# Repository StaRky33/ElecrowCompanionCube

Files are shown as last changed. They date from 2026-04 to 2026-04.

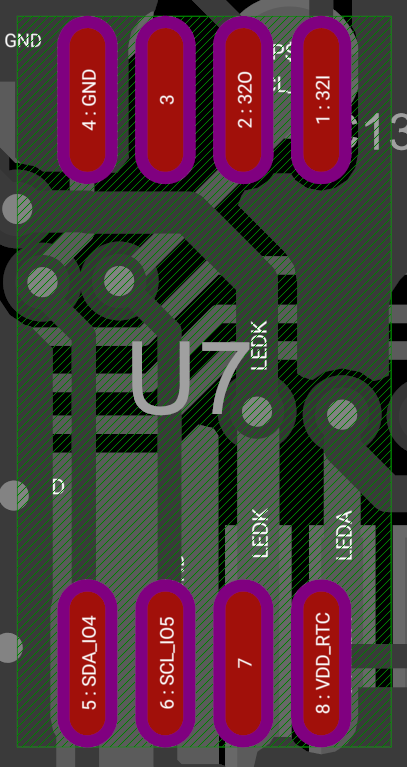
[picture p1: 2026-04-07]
Docs/PCB_BM8563_pinout.png

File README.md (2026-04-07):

# Elecrow Companion Cube

A DIY smart desk clock built on the **Elecrow CrowPanel ESP32 1.28" Round Display**, inspired by [Huy Vector's Smart Cyber Clock V2](https://www.huyvector.org/smart-cyber-clock-v2) and shaped like a Portal Companion Cube.

Displays real-time clock, temperature, humidity, air quality (eCO2/TVOC), with an onboard buzzer alert for dangerous CO2 levels. Time is maintained by a hardware RTC (BM8563) with battery backup — no network required after initial sync.

---

## Features

- Real-time clock via **BM8563 RTC** (coin cell backup, survives power loss)
- NTP sync on first boot to set the RTC (France / GMT+2 CEST)
- Air quality monitoring: **temperature, humidity, eCO2, TVOC** via ENS160 + AHT sensor
- CO2 danger alert via onboard **buzzer**
- Round 240×240 IPS display with clean sensor dashboard
- Fully offline after initial WiFi sync

---

## Hardware

| Component | Details |
|---|---|
| Main board | Elecrow CrowPanel ESP32-C3 1.28" Round Display |
| Air quality sensor | ENS160 + AHT21 combo module |
| Display | GC9A01 round IPS 240×240 (onboard) |
| RTC | BM8563 with CR927 coin cell (onboard) |
| Buzzer | Passive buzzer (onboard, IO3) |

> See [`BOM.md`](BOM.md) for full bill of materials with links.

---

## Wiring

The ENS160+AHT sensor connects directly to the BM8563 RTC pads on the back of the board:

| Sensor pin | Board pad |
|---|---|
| SDA | BM8563 SDA (IO4) |
| SCL | BM8563 SCL (IO5) |
| VCC | 3.3V |
| GND | GND |

> All three devices (BM8563, ENS160, AHT) share the same I2C bus.  
> See [`wiring.md`](wiring.md) for detailed soldering instructions and I2C addresses.

---

## Software

### Requirements

- Arduino IDE 2.x
- Board: **ESP32C3 Dev Module** (esp32 by Espressif Systems 2.0.14+)
- **USB CDC On Boot**: Enabled (required for Serial Monitor)

### Libraries

Install via Arduino Library Manager:

| Library | Purpose |
|---|---|
| `Arduino_GFX_Library` | GC9A01 display driver |
| `I2C BM8563` | RTC chip |
| `Adafruit AHTX0` | Temperature & humidity |
| `ScioSense ENS160` | eCO2 & TVOC |
| `Adafruit BusIO` | I2C/SPI dependency |

### Configuration

In `Arduino/CompanionCube.ino`, set your WiFi credentials before uploading:

```cpp
const char* ssid     = "your_wifi_name";
const char* password = "your_wifi_password";
```

The timezone is set to **France (GMT+2 CEST)**:
```cpp
configTime(2 * 3600, 0, ntpServer);
```
Adjust the multiplier if needed (e.g. `1 * 3600` for winter CET).

Once the RTC is synced from NTP on first boot, WiFi is disconnected and the clock runs fully offline.

### ENS160 status

The ENS160+AHT sensor is enabled via a `#define` flag at the top of the sketch:

```cpp
#define ENS160_READY false  // set to true once sensor is soldered
```

When `false`, the display shows simulated sensor values labeled `(fake)`.

---

## Project Structure

```
Elecrow-Companion-Cube/
|   .gitignore
|   BOM.md
|   LICENSE
|   README.md
|   wiring.md
|
+---3DModels
|       Angle.stl
|       Body_plate.stl
|       CrowPanel ESP32 Display1.28_asm.stl
|       CrowPanel ESP32 Display1.28_asm.stp
|       Edge.stl
|       Heart_insert.stl
|       Heart_medal.stl
|       Weighted_Companion_Cube.stl
|
+---Arduino
|       CompanionCube.ino
|
\---Docs
        CrowPanel ESP32 Display 1.28(R) Inch_V1.0_240507.brd
        CrowPanel ESP32 Display 1.28(R) Inch_V1.0_240507.pdf
        PCB_BM8563.png
        PCB_BM8563_pinout.png
```

---

## License

MIT — see [`LICENSE`](LICENSE)

---

## Credits

Original design concept by [Huy Vector](https://www.huyvector.org/smart-cyber-clock-v2).
Original Companion Cube by [Poh](https://www.thingiverse.com/thing:33138)
Remixed Companion Cube by [Nuk1591](https://www.thingiverse.com/thing:2981843)

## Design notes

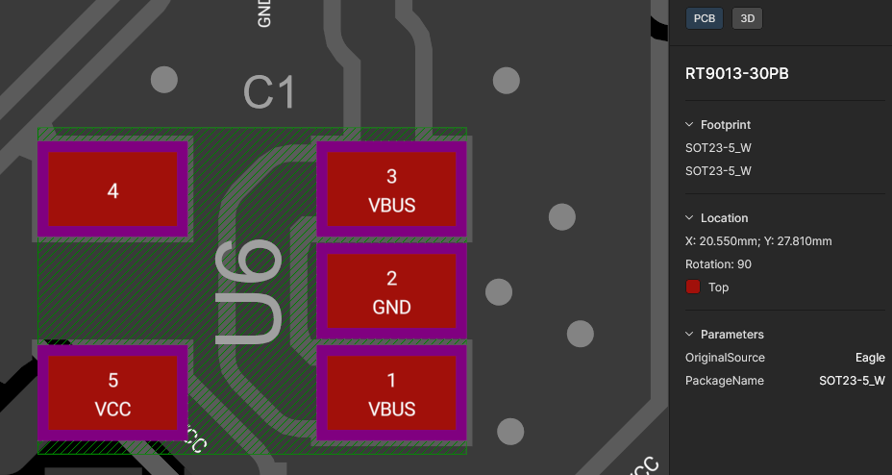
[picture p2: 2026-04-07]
Docs/PCB_RT9013_pinout.png

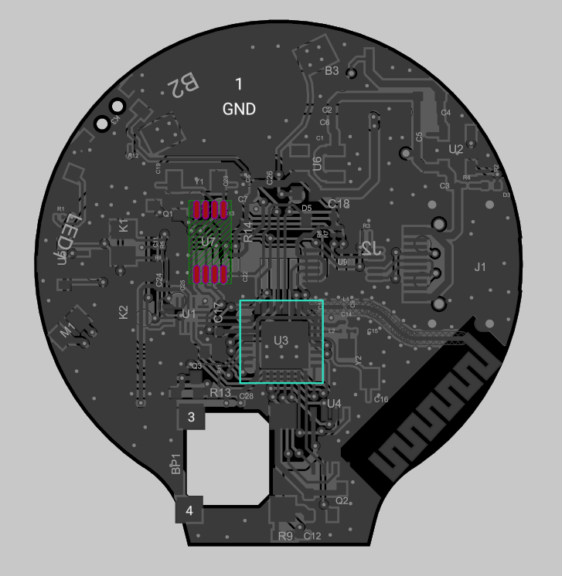
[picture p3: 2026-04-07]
Docs/PCB_BM8563.png

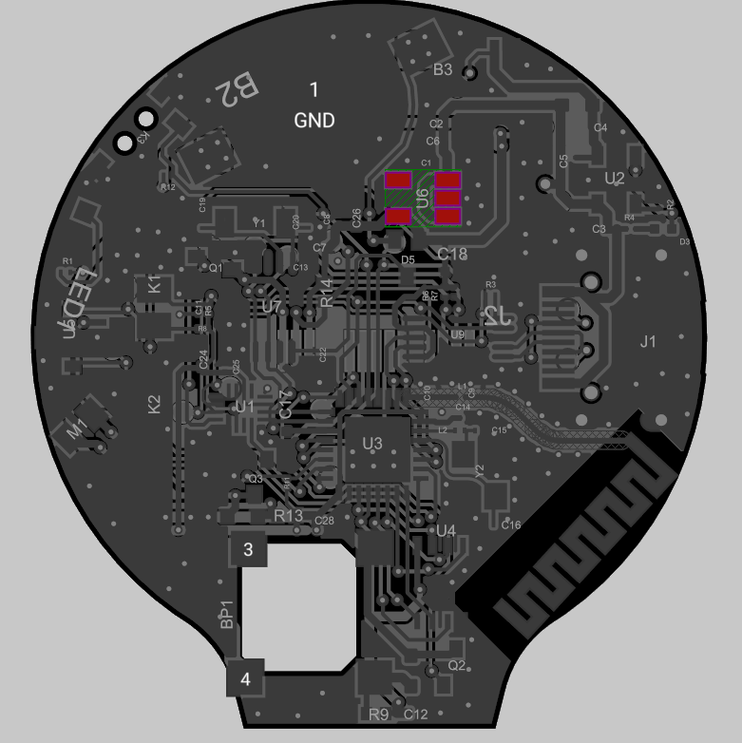
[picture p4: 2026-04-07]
Docs/PCB_RT9013.png

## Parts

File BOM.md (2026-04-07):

# Bill of Materials

All components used in the Smart Cyber Clock V2 build.

---

## Main Board

| Component | Description | Link |
|---|---|---|
| Elecrow CrowPanel ESP32 1.28" | ESP32-C3, GC9A01 round display 240×240, BM8563 RTC, buzzer, CR927 battery holder, Type-C, LiPo connector | [Elecrow](https://www.elecrow.com/crowpanel-esp32-display-1-28-r-inch-240-240-round-ips-display-capacitive-touch-spi-screen.html) |
| CR927 coin cell | Powers the BM8563 RTC when the board is off | Local / Amazon |

---

## Sensors

| Component | Description | Notes |
|---|---|---|
| ENS160 + AHT21 combo module | eCO2, TVOC, temperature, humidity over I2C | Soldered directly to BM8563 SDA/SCL pads |

---

## Power

| Component | Description | Notes |
|---|---|---|
| LiPo battery | 3.7V, any capacity (recommended 500mAh+) | Plugs into onboard SH1.0 2-pin connector |
| USB-C cable | For charging and firmware upload | Standard |

> The Elecrow board has an integrated LiPo charger — no external charging module needed.

---

## Tools

| Tool | Purpose |
|---|---|
| Soldering iron | Attaching ENS160 wires to BM8563 pads |
| Fine enamelled wire / magnet wire | I2C connections to SMD pads |
| Multimeter | Continuity check before powering up |

---

## Notes

- The ENS160+AHT module shares the I2C bus with the onboard BM8563 RTC (`SDA=IO4`, `SCL=IO5`)
- Make sure your ENS160 breakout board has onboard pull-up resistors (most do). If not, add 4.7kΩ from SDA and SCL to 3.3V.
- The backlight on this board is controlled via the **PI4IOE5V6408 I/O expander** (I2C address `0x43`), not a direct GPIO pin.

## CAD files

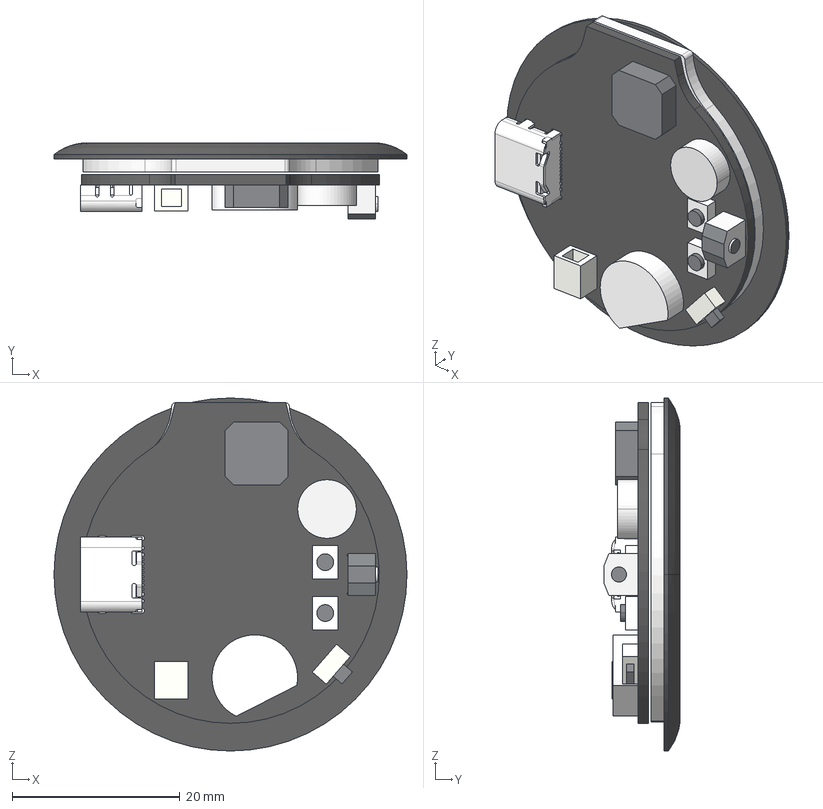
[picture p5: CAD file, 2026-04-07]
3DModels/CrowPanel ESP32 Display1.28_asm.stp
42.1 x 9.10 x 42.1 mm
LCD-MIANBAN
LCD-JIAOTIE
PCB
TYPE_C_20241129

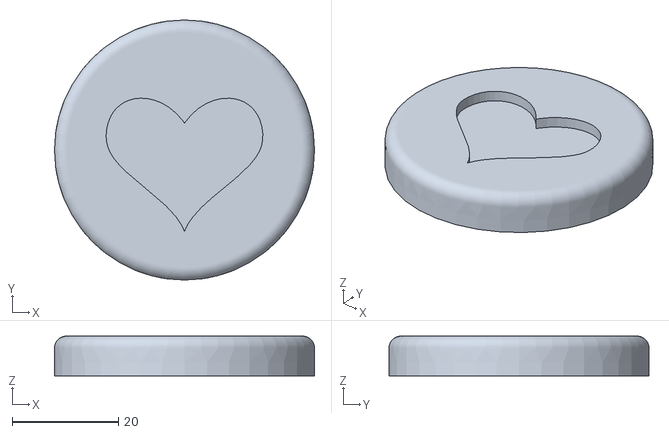
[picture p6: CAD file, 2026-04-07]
3DModels/Heart_medal.stl
48.9 x 48.9 x 7.50

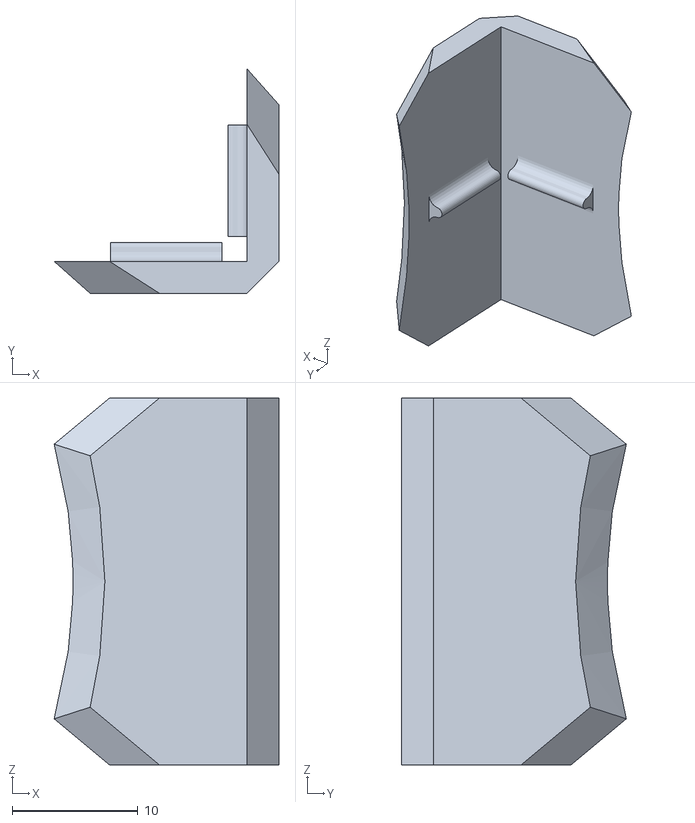
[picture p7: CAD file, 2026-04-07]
3DModels/Angle.stl
17.9 x 17.9 x 29.2

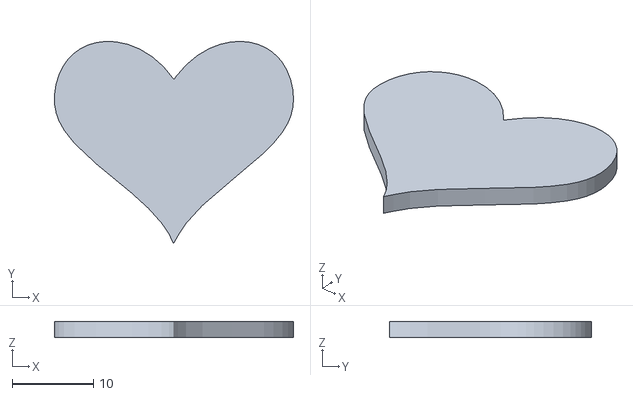
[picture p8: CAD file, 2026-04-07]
3DModels/Heart_insert.stl
29.5 x 24.9 x 2.00

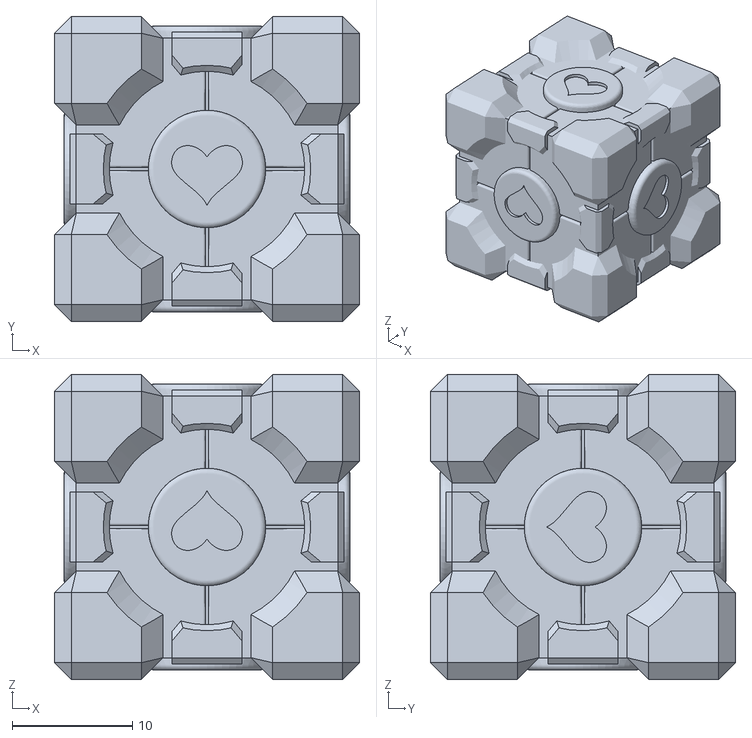
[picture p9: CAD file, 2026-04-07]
3DModels/Weighted_Companion_Cube.stl
25.4 x 25.4 x 25.4

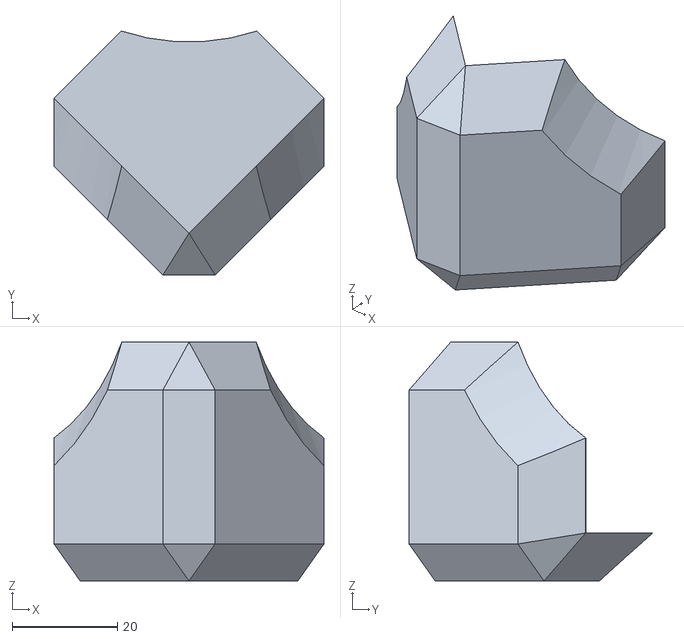
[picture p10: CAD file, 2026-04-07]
3DModels/Edge.stl
51.2 x 46.2 x 45.3

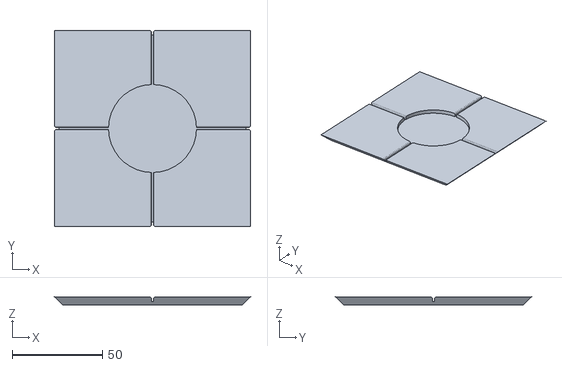
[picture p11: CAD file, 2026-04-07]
3DModels/Body_plate.stl
108.9 x 108.9 x 4.50

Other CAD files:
3DModels/CrowPanel ESP32 Display1.28_asm.stl

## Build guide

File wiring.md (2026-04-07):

# Wiring Notes

## I2C Bus

All I2C devices share a single bus on the Elecrow CrowPanel 1.28":

| Signal | GPIO |
|---|---|
| SDA | IO4 |
| SCL | IO5 |

### Devices on the bus

| Device | I2C Address | Purpose |
|---|---|---|
| BM8563 | `0x51` | RTC (onboard) |
| PI4IOE5V6408 | `0x43` | I/O expander — controls backlight (onboard) |
| ENS160 | `0x53` | Air quality sensor (soldered externally) |
| AHT21 | `0x38` | Temperature & humidity (soldered externally) |

---

## ENS160 + AHT Soldering

The ENS160+AHT module has no dedicated external connector on this board.
Solder fine wires directly to the **BM8563 RTC pads** on the back of the PCB.

```
ENS160/AHT module          CrowPanel board (back)
─────────────────          ──────────────────────
VCC  ──────────────────►  3.3V pad
GND  ──────────────────►  GND pad
SDA  ──────────────────►  BM8563 SDA pad (IO4)
SCL  ──────────────────►  BM8563 SCL pad (IO5)
```

> Use the thinnest wire available (enamelled / magnet wire works well).
> Keep wires short to avoid I2C signal integrity issues.
> Verify continuity with a multimeter before powering up.

---

## Backlight

The display backlight is **not** controlled by a direct GPIO. It is routed through the **PI4IOE5V6408 I/O expander** via I2C. The firmware handles this automatically in `setup()` — no hardware change needed.

---

## Power

The board accepts a **3.7V LiPo battery** via its onboard SH1.0 2-pin connector.
Charging is handled by the onboard circuit via the **USB-C port**.
No external charging module is required.

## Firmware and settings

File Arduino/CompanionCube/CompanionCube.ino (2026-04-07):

#define LGFX_USE_V1
#include <Arduino.h>
#include <WiFi.h>
#include <Wire.h>
#include <LovyanGFX.hpp>
#include <I2C_BM8563.h>
#include "secrets.h"

/* ── WIFI ───────────────────────────────────────────────────── */
const char* ssid = WIFI_SSID;
const char* password = WIFI_PASSWORD;
const char* ntpServer = "pool.ntp.org";

/* ── I2C ────────────────────────────────────────────────────── */
#define I2C_SDA 4
#define I2C_SCL 5

/* ── IO EXPANDER ────────────────────────────────────────────── */
#define PI4IO_I2C_ADDR 0x43

/* ── BUZZER ─────────────────────────────────────────────────── */
#define BUZZER_PIN 3

/* ── RTC (BM8563) ───────────────────────────────────────────── */
I2C_BM8563 rtc(I2C_BM8563_DEFAULT_ADDRESS, Wire);
I2C_BM8563_DateTypeDef rtcDate;
I2C_BM8563_TimeTypeDef rtcTime;

/* ── ENS160 + AHT - faked until soldered ───────────────────── */
#define ENS160_READY false

/* ── FAKE SENSOR DATA ───────────────────────────────────────── */
float fakeTemp = 21.5;
float fakeHum = 48.0;
uint16_t fakeEco2 = 650;
uint16_t fakeTvoc = 120;

/* ── LIVE DATA ──────────────────────────────────────────────── */
float temp = 21.5;
float hum = 48.0;
uint16_t eco2 = 650;
uint16_t tvoc = 120;

/* ── TIMERS ─────────────────────────────────────────────────── */
unsigned long lastSensor = 0;
unsigned long lastSerial = 0;

/* ── CLOCK CACHE ────────────────────────────────────────────── */
int prevHour = 0;
int prevMin = 0;
int prevSec = 0;

/* ── DISPLAY (LovyanGFX - GC9A01) ──────────────────────────── */
class LGFX : public lgfx::LGFX_Device {
  lgfx::Panel_GC9A01 _panel_instance;
  lgfx::Bus_SPI _bus_instance;

public:
  LGFX(void) {
    {
      auto cfg = _bus_instance.config();
      cfg.spi_host = SPI2_HOST;
      cfg.spi_mode = 0;
      cfg.freq_write = 80000000;
      cfg.freq_read = 20000000;
      cfg.spi_3wire = true;
      cfg.use_lock = true;
      cfg.dma_channel = SPI_DMA_CH_AUTO;
      cfg.pin_sclk = 6;
      cfg.pin_mosi = 7;
      cfg.pin_miso = -1;
      cfg.pin_dc = 2;
      _bus_instance.config(cfg);
      _panel_instance.setBus(&_bus_instance);
    }
    {
      auto cfg = _panel_instance.config();
      cfg.pin_cs = 10;
      cfg.pin_rst = -1;
      cfg.pin_busy = -1;
      cfg.memory_width = 240;
      cfg.memory_height = 240;
      cfg.panel_width = 240;
      cfg.panel_height = 240;
      cfg.offset_x = 0;
      cfg.offset_y = 0;
      cfg.offset_rotation = 0;
      cfg.dummy_read_pixel = 8;
      cfg.dummy_read_bits = 1;
      cfg.readable = false;
      cfg.invert = true;
      cfg.rgb_order = false;
      cfg.dlen_16bit = false;
      cfg.bus_shared = false;
      _panel_instance.config(cfg);
    }
    setPanel(&_panel_instance);
  }
};

LGFX tft;

/* ── COLORS ─────────────────────────────────────────────────── */
#define BLACK 0x0000
#define WHITE 0xFFFF
#define CYAN 0x07FF
#define GREEN 0x07E0
#define YELLOW 0xFFE0
#define ORANGE 0xFD20
#define RED 0xF800
#define GRAY 0x8410
#define DKGRAY 0x4208

/* ══════════════════════════════════════════════════════════════
   IO EXPANDER - copied exactly from factory demo
   ══════════════════════════════════════════════════════════════ */
void init_IO_extender() {
  Wire.beginTransmission(PI4IO_I2C_ADDR);
  Wire.write(0x01);
  Wire.endTransmission();
  Wire.requestFrom(PI4IO_I2C_ADDR, 1);
  uint8_t rxdata = Wire.read();
  Serial.print("IO Expander ID: ");
  Serial.println(rxdata, HEX);

  Wire.beginTransmission(PI4IO_I2C_ADDR);
  Wire.write(0x03);
  Wire.write((1 << 0) | (1 << 1) | (1 << 2) | (1 << 3) | (1 << 4));
  Wire.endTransmission();

  Wire.beginTransmission(PI4IO_I2C_ADDR);
  Wire.write(0x07);
  Wire.write(~((1 << 0) | (1 << 1) | (1 << 2) | (1 << 3) | (1 << 4)));
  Wire.endTransmission();
}

void set_pin_io(uint8_t pin_number, bool value) {
  Wire.beginTransmission(PI4IO_I2C_ADDR);
  Wire.write(0x05);
  Wire.endTransmission();
  Wire.requestFrom(PI4IO_I2C_ADDR, 1);
  uint8_t rxdata = Wire.read();

  Wire.beginTransmission(PI4IO_I2C_ADDR);
  Wire.write(0x05);
  if (!value)
    Wire.write((~(1 << pin_number)) & rxdata);
  else
    Wire.write((1 << pin_number) | rxdata);
  Wire.endTransmission();
}

/* ══════════════════════════════════════════════════════════════
   BUZZER
   ══════════════════════════════════════════════════════════════ */
void beep(int freq, int time_ms) {
  tone(BUZZER_PIN, freq);
  delay(time_ms);
  noTone(BUZZER_PIN);
}

/* ══════════════════════════════════════════════════════════════
   WIFI + NTP
   ══════════════════════════════════════════════════════════════ */
void syncRTCFromNTP() {
  Serial.print("Connecting to WiFi");
  WiFi.begin(ssid, password);
  int attempts = 0;
  while (WiFi.status() != WL_CONNECTED && attempts < 20) {
    delay(500);
    Serial.print(".");
    attempts++;
  }

  if (WiFi.status() == WL_CONNECTED) {
    Serial.println(" connected!");
    configTime(2 * 3600, 0, ntpServer);

    struct tm timeinfo;
    int ntpAttempts = 0;
    while (!getLocalTime(&timeinfo) && ntpAttempts < 10) {
      delay(500);
      ntpAttempts++;
    }

    if (getLocalTime(&timeinfo)) {
      rtcTime.hours = timeinfo.tm_hour;
      rtcTime.minutes = timeinfo.tm_min;
      rtcTime.seconds = timeinfo.tm_sec;
      rtc.setTime(&rtcTime);

      rtcDate.year = timeinfo.tm_year + 1900;
      rtcDate.month = timeinfo.tm_mon + 1;
      rtcDate.date = timeinfo.tm_mday;
      rtc.setDate(&rtcDate);

      Serial.println("RTC synced from NTP.");
    } else {
      Serial.println("NTP sync failed.");
    }

    WiFi.disconnect(true);
    WiFi.mode(WIFI_OFF);
    Serial.println("WiFi disconnected.");
  } else {
    Serial.println(" WiFi failed — RTC keeps existing time.");
  }
}

/* ══════════════════════════════════════════════════════════════
   CLOCK
   ══════════════════════════════════════════════════════════════ */
void updateClock() {
  rtc.getTime(&rtcTime);
  prevHour = rtcTime.hours;
  prevMin = rtcTime.minutes;
  prevSec = rtcTime.seconds;
}

/* ══════════════════════════════════════════════════════════════
   AIR SENSORS
   ══════════════════════════════════════════════════════════════ */
void readAir() {
  if (ENS160_READY) {
    // Uncomment once ENS160 + AHT are soldered:
    // sensors_event_t humidity, tempEvent;
    // if (aht.getEvent(&humidity, &tempEvent)) {
    //   temp = tempEvent.temperature;
    //   hum  = humidity.relative_humidity;
    // }
    // ens160.set_envdata(temp, hum);
    // ens160.measure();
    // eco2 = ens160.geteCO2();
    // tvoc = ens160.getTVOC();
  } else {
    fakeTemp += random(-5, 6) * 0.1f;
    fakeHum += random(-3, 4) * 0.1f;
    fakeTemp = constrain(fakeTemp, 18.0, 28.0);
    fakeHum = constrain(fakeHum, 35.0, 65.0);
    temp = fakeTemp;
    hum = fakeHum;
    eco2 = fakeEco2;
    tvoc = fakeTvoc;
  }
}

/* ══════════════════════════════════════════════════════════════
   AQI HELPERS
   ══════════════════════════════════════════════════════════════ */
int getAQILevel() {
  if (eco2 < 800) return 0;
  else if (eco2 < 1200) return 1;
  else if (eco2 < 1800) return 2;
  else return 3;
}

String getAQILabel(int level) {
  if (level == 0) return "Good";
  else if (level == 1) return "Moderate";
  else if (level == 2) return "Poor";
  else return "DANGER";
}

uint16_t getAQIColor(int level) {
  if (level == 0) return GREEN;
  else if (level == 1) return YELLOW;
  else if (level == 2) return ORANGE;
  else return RED;
}

/* ══════════════════════════════════════════════════════════════
   DISPLAY - static background
   ══════════════════════════════════════════════════════════════ */
void drawStaticUI()
{
  tft.fillScreen(WHITE);

  tft.drawCircle(120, 120, 118, DKGRAY);
  tft.drawCircle(120, 120, 116, DKGRAY);

  tft.drawFastHLine(25, 85,  190, DKGRAY);
  tft.drawFastHLine(25, 158, 190, DKGRAY);
  tft.drawFastVLine(120, 85, 73, DKGRAY);

  tft.setTextSize(1);
  tft.setTextColor(GRAY);

  tft.setCursor(34, 92);
  tft.print("HUMIDITY");

  tft.setCursor(130, 92);
  tft.print("TEMP");

  tft.setCursor(40, 164);
  tft.print("TVOC");

  tft.setCursor(130, 164);
  tft.print("eCO2");

  if (!ENS160_READY) {
    tft.setTextColor(DKGRAY);
    tft.setCursor(81, 220);
    tft.print("* SIMULATED *");
  }
}

void drawSplashScreen()
{
  tft.fillScreen(WHITE);

  int cx = 120;
  int cy = 125;

  tft.fillCircle(cx - 25, cy - 20, 30, 0xF800);  // RED
  tft.fillCircle(cx + 25, cy - 20, 30, 0xF800);

  tft.fillTriangle(
    cx - 52, cy - 5,
    cx + 52, cy - 5,
    cx,      cy + 50,
    0xF800
  );

  delay(2000);
}

/* ══════════════════════════════════════════════════════════════
   DISPLAY - live values
   ══════════════════════════════════════════════════════════════ */

void drawValues()
{
  int      level    = getAQILevel();
  uint16_t aqiColor = getAQIColor(level);

  // ── Time (centered) ──
  char timeBuf[9];
  snprintf(timeBuf, sizeof(timeBuf), "%02d:%02d:%02d", prevHour, prevMin, prevSec);
  tft.fillRect(40, 35, 160, 45, WHITE);
  tft.setTextSize(3);
  tft.setTextColor(RED);
  tft.setCursor(48, 48);
  tft.print(timeBuf);

  // ── Humidity (left cell) ──
  tft.fillRect(25, 105, 90, 48, WHITE);
  tft.setTextSize(2);
  tft.setTextColor(RED);
  tft.setCursor(42, 118);
  tft.print((int)hum);
  tft.print("%");

  // ── Temperature (right cell) ──
  tft.fillRect(122, 105, 90, 48, WHITE);
  tft.setTextSize(2);
  tft.setTextColor(CYAN);
  tft.setCursor(150, 118);
  tft.print(temp, 1);
  tft.print("C");

  // ── TVOC (left cell, more centered) ──
  tft.fillRect(30, 174, 84, 28, WHITE);  
  tft.setTextSize(2);
  tft.setTextColor(BLACK);
  // "120ppb" = 6 chars * 12px = 72px, center of left cell (25+90/2=70) = start at 34
  tft.setCursor(34, 178);
  tft.print(tvoc);
  tft.print("ppb");

  // ── eCO2 (right cell, more centered) ──
  tft.fillRect(126, 174, 84, 28, WHITE); 
  tft.setTextSize(2);
  tft.setTextColor(aqiColor);
  // "650ppm" = 6 chars * 12px = 72px, center of right cell (122+90/2=167) = start at 131
  tft.setCursor(131, 178);
  tft.print(eco2);
  tft.print("ppm");

  // ── AQI label (centered) ──
  tft.fillRect(60, 200, 120, 18, WHITE);
  tft.setTextSize(2);
  tft.setTextColor(aqiColor);
  String label = getAQILabel(level);
  int labelX = 120 - (label.length() * 6);
  tft.setCursor(labelX, 202);
  tft.print(label);

  if (level == 3) beep(3000, 40);
}


/* ══════════════════════════════════════════════════════════════
   SERIAL OUTPUT
   ══════════════════════════════════════════════════════════════ */
void printSerial() {
  int level = getAQILevel();
  Serial.println("================================");
  Serial.printf("Time     : %02d:%02d:%02d\n", prevHour, prevMin, prevSec);
  Serial.print("Temp     : ");
  Serial.print(temp, 1);
  Serial.println(ENS160_READY ? " C" : " C (fake)");
  Serial.print("Humidity : ");
  Serial.print(hum, 0);
  Serial.println(ENS160_READY ? " %" : " % (fake)");
  Serial.print("eCO2     : ");
  Serial.print(eco2);
  Serial.println(ENS160_READY ? " ppm" : " ppm (fake)");
  Serial.print("TVOC     : ");
  Serial.print(tvoc);
  Serial.println(ENS160_READY ? " ppb" : " ppb (fake)");
  Serial.print("Air      : ");
  Serial.print(getAQILabel(level));
  Serial.print(" (level ");
  Serial.print(level);
  Serial.println(")");
  Serial.println("RTC      : hardware BM8563");
  Serial.println("================================");
}

/* ══════════════════════════════════════════════════════════════
   SETUP
   ══════════════════════════════════════════════════════════════ */
void setup() {
  Serial.begin(115200);
  delay(200);
  Serial.println("Booting Companion Cube...");

  // I2C init
  Wire.begin(I2C_SDA, I2C_SCL);

  // IO expander init
  init_IO_extender();
  delay(100);
  set_pin_io(3, true);
  set_pin_io(4, true);
  delay(100);

  // Display init
  tft.init();
  tft.setColorDepth(16);
  tft.endWrite();
  delay(200);

  // Backlight on after display init
  set_pin_io(2, true);
  delay(100);
  drawSplashScreen();
  // RTC init
  rtc.begin();
  Serial.println("BM8563 RTC ready.");

  // Sync RTC from NTP
  syncRTCFromNTP();

  // Initial sensor read
  readAir();

  // Draw UI
  drawStaticUI();

  // Boot beep
  beep(1000, 80);

  Serial.println("Setup complete.");
}
/* ══════════════════════════════════════════════════════════════
   LOOP
   ══════════════════════════════════════════════════════════════ */
void loop() {
  updateClock();

  if (millis() - lastSensor > 5000) {
    lastSensor = millis();
    readAir();
  }

  drawValues();

  if (millis() - lastSerial > 2000) {
    lastSerial = millis();
    printSerial();
  }

  delay(1000);
}

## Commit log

2026-04-07 First commit
    Basic project working with simulated values for ENS160+AHT2X and No Gyro
    [Angle.stl, Body_plate.stl, CrowPanel ESP32 Display1.28_asm.stl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]
2026-04-07 Add doc pictures to get 3.3V and GND
2026-04-07 Use autoformat to fix minor UI issue.
    [CompanionCube.ino]
2026-04-07 Add splashscreen heart and fix color issues with UI.
    [CompanionCube.ino]
2026-04-07 Improve UI and fix rect to avoid grey cutout.
    [CompanionCube.ino]
